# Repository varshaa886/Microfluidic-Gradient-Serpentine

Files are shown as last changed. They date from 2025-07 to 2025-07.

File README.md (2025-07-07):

# Microfluidic-Gradient-Serpentine
Analysis of dye diffusion and gradient formation in a 3 cm serpentine microchannel designed for microfluidic experiments using SolidWorks and 3D-printed molds.

Course: ME224 – Microscale Flows
Department of Mechanical Engineering, IIT Indore
Course Coordinator: Dr. Vijai Laxmi (Assistant Professor)
Team Members:

Sumit Sarkar (230003075)

Sri Varsha Dodda (230003074)

Shreeyut Maheshwari (230003071)

Project Title
Studying Diffusion and Fluid Flow for Gradient Formation in Microfluidic Platforms

Overview
This project explores the dynamics of fluid mixing and diffusion in microfluidic channels to create controlled concentration gradients. A serpentine microfluidic mixer was designed, simulated, and fabricated for biomedical and chemical mixing applications such as drug screening and lab-on-a-chip devices.

Literature Review
The design and methodology were inspired by the following research works:

Paper 1: Microfluidic systems using laminar flow splitting and recombination for static and dynamic gradients.

Paper 2: Comparative study on gradient generators including tree-shaped, Y-junction, and pressure balance systems.

Objective
To study and analyze fluid flow and diffusion-based gradient formation in a microfluidic serpentine channel, using numerical simulations and experimental validation.

Methodology
1. CAD Modelling
Designed a serpentine microchannel with two inlets and one outlet.

Dimensions: 40mm × 47mm with a total channel length of 31.75mm.

2. Simulation (ANSYS Fluent 2024 R1)
Eulerian Mixture Model for laminar flow (Re < 1).

Governing equations: Continuity, Momentum, and Species Transport (Fick's Law).

Boundary conditions: Specified inlet velocity, gauge pressure outlet.

3. Fabrication
Soft lithography using PDMS and resin mold.

Device bonded to a glass substrate.

4. Experimentation
Injected red and blue dye solutions at a flow rate of 0.2 ml/min.

Observed mixing behavior and gradient formation.

Results & Analysis
Hydraulic Diameter (Dh): 204.87 µm

Reynolds Number (Re): 0.02

Peclet Number (Pe): 205 (advection-dominated transport)

Achieved uniform gradients under different inlet velocity ratios (1:1 and 1:2).

Observed anomalous diffusion behavior.

Numerical vs Analytical Hydraulic Resistance: ~6% error only.

Conclusion
A controllable concentration gradient was successfully achieved through a serpentine microfluidic design.

Simulation and experimental results confirm the role of inlet velocity in gradient slope control.

Analytical and numerical agreement shows the model's reliability.

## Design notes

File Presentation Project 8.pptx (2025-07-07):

## ME224 - Microscale Flows

Studying Diffusion and Fluid flow for gradient Formation in microfluidic platforms

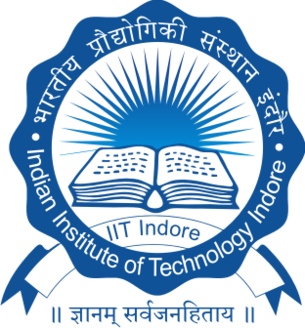
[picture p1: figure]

Department of Mechanical Engineering
Indian Institute of Technology Indore

Course Coordinator :
Dr. Vijai Laxmi
Assistant Professor
Department of Mechanical Engineering

Presented by :
Group Members
Sumit Sarkar(230003075)
Sri Varsha Dodda(230003074)
Shreeyut Maheshwari(230003071)

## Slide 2

Content

- Introduction
- Literature review
- Motivation and Objective
- Methodology
- Results and discussions
- Conclusion
- Future scope
- References

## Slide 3

Introduction

Microfluidic systems are widely used for precise fluid control in biomedical, chemical, and analytical applications. This project focuses on designing a serpentine microfluidic mixer to create a controlled gradient by mixing two inlet streams: red and blue resulting in a purple gradient transition.

The design was simulated in ANSYS Fluent to analyze fluid flow and diffusion. It was then fabricated using PDMS and a curing agent, molded, and baked. This study optimizes gradient formation for lab-on-a-chip and chemical mixing applications.

Reference of image: Link (https://ht.cnhealthshining.net/digital-thermometer/blood-analyzer-machine.html)

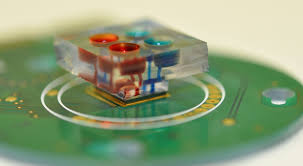
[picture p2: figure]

Fig. 1 Bioengineering Application

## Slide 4

Literature Review

- Our Project was mainly based on two Research Papers:
  - Paper 1[1]: This study presents a microfluidic system that generates precise gradients through controlled mixing of laminar flows. It achieves this by splitting, mixing, and recombining streams, allowing for both static (fixed) and dynamic (adjustable) gradient profiles based on flow rate variations.

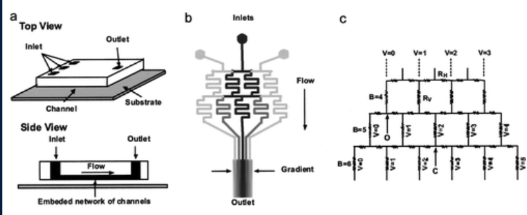
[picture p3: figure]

Literature Review

Fig. 1[¹] (a) Scheme of the PDMS microfluidic gradient generator used in this work. (b) Schematic design of a representative gradient-generating microfluidic network.(c) Equivalent electronic circuit model of the pyramidal microfluidic network.

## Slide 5

Literature Review

Our Project was mainly based on two Research Papers:
- Paper 2[2]: Various gradient generators in microfluidics were analyzed, highlighting their pros and cons.
- Tree-shaped networks create gradients by branching and recombining streams, while altered tree networks address limitations of traditional designs.

Literature Review

- Y-junctions rely on diffusion, membrane systems use porous barriers, and pressure balance systems prevent convection by equalizing inlet and outlet pressures.

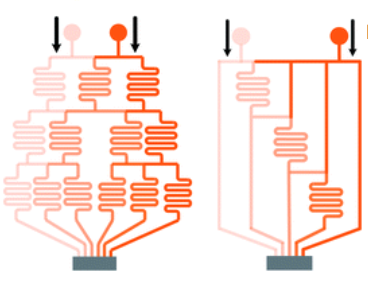
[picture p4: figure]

Fig2[2].Altered Tree Shape Diagram

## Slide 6

Motivation and objectives

Motivation
- Microfluidic systems are essential in biomedical and chemical research, enabling precise fluid control for applications like drug screening, tissue engineering, and chemical analysis. Efficient gradient formation is critical for these processes, requiring a deep understanding of diffusion and fluid flow dynamics in microchannels. This project aims to enhance microfluidic design for optimized gradient generation, contributing to advancements in lab-on-a-chip technology and controlled chemical mixing.

Objective
- To study diffusion and fluid flow dynamics for gradient formation in microfluidic platforms by designing a serpentine mixer, simulating fluid behavior in ANSYS Fluent, and fabricating the device using PDMS.

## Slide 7

Methodology

- Research Phase
  - We reviewed papers on gradient formation to understand diffusion dynamics and microfluidic mixing strategies

- Cad Modelling
  - The microfluidic mixer features three serpentine channels with two inlets for red and blue fluids. A single outlet allows observation of the resulting purple gradient formation.
  - Total Length : 31.75 mm
  - 40 mm by 47 mm Mold

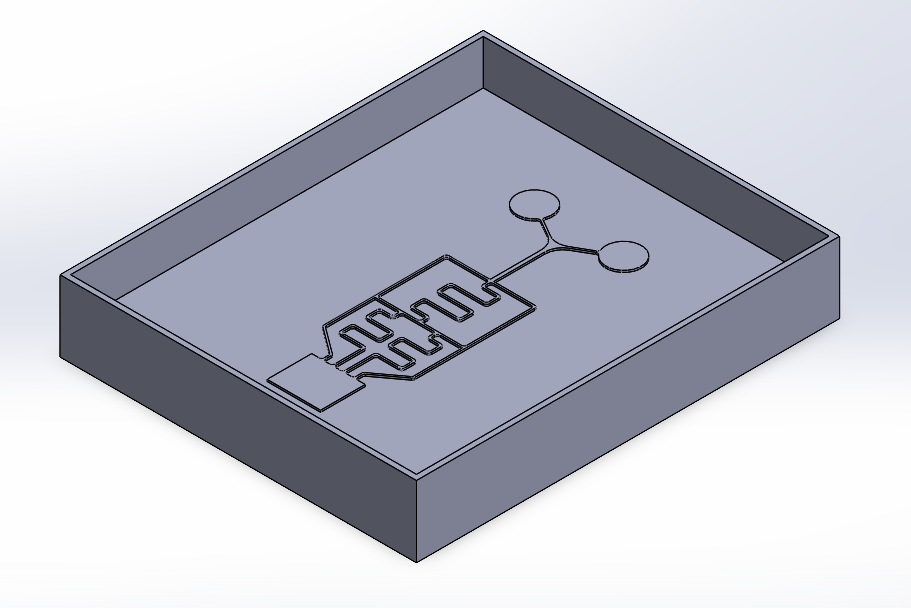
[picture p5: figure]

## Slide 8

Methodology

- Simulation
  - Simlulated on Ansys Fluent 2024 R1
  - We used the Eulerian mixture model for laminar flow (Re<1). Continuity , Momentum equations solved and Species Transport to apply Fick’s law of diffusion.
  - Boundary Conditions
    - Inlet Velocity
    - Gauge Pressure = 0 along with no shear

- Fabrication
  - Soft Lithography
  - The resin mold was fabricated, cleaned, and cured. PDMS was poured, baked, peeled off, and bonded to a glass plate.

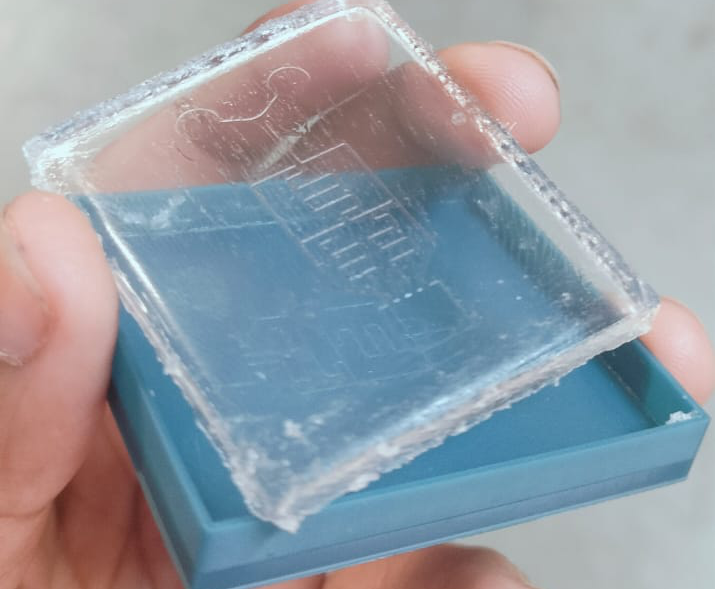
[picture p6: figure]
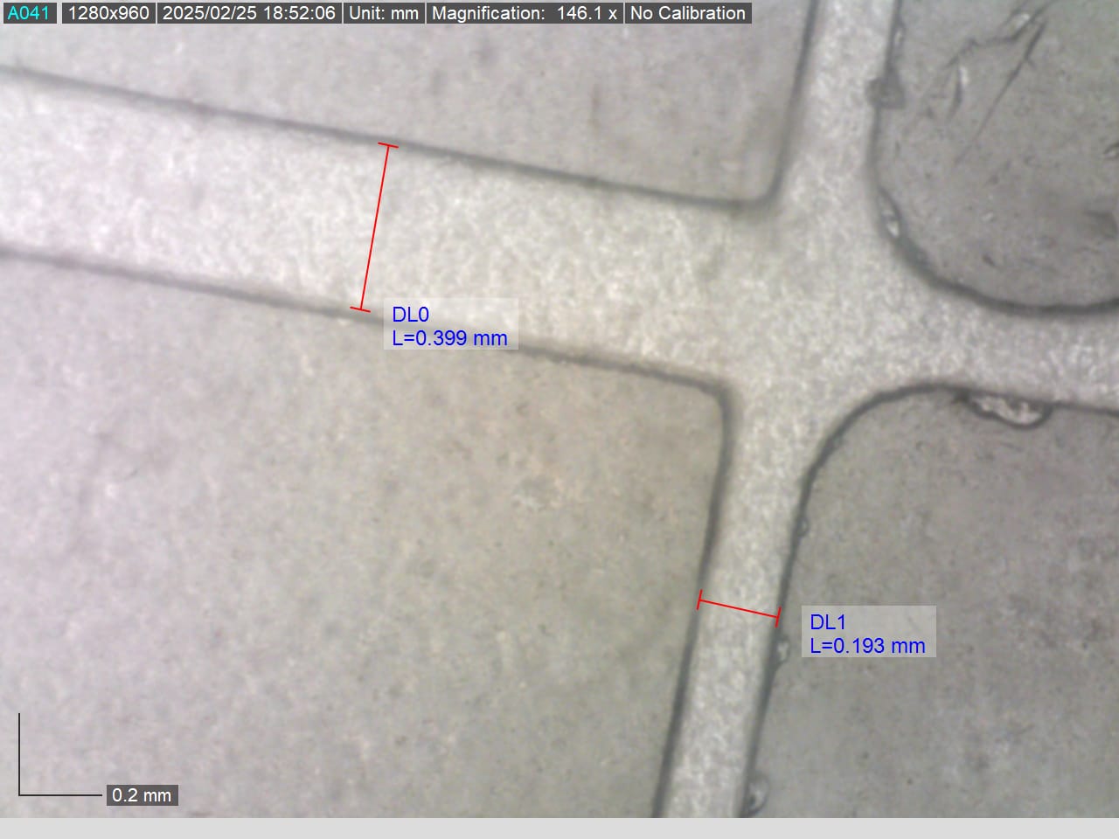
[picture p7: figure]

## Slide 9

Methodology

- Experimenting
  - Preparation of Dyes: Two separate dye solutions, red and blue, were prepared.
  - Injection into Inlets: The dyes were carefully poured into their respective microfluidic inlets.A volume flow rate of 0.2ml/min was set.
  - Gradient Formation: As the fluids traveled through the serpentine channels, controlled mixing occurred.

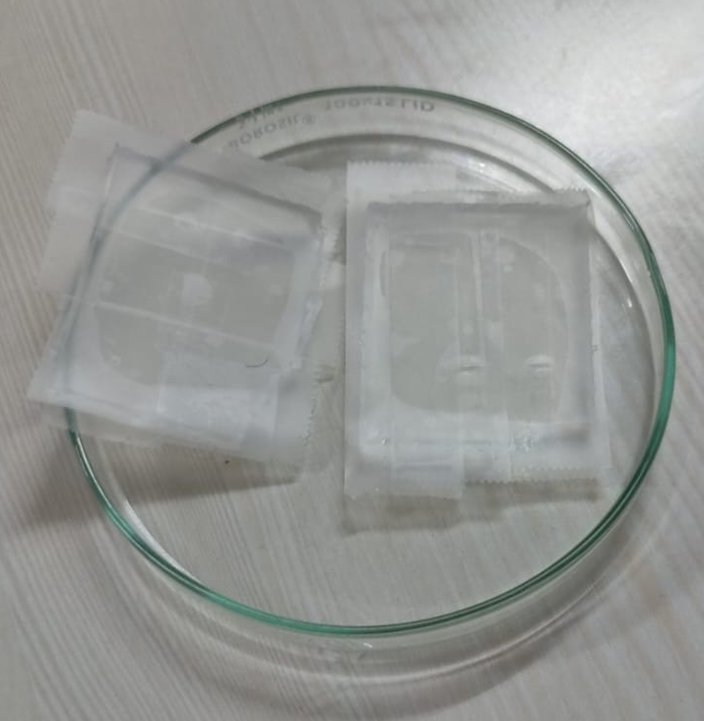
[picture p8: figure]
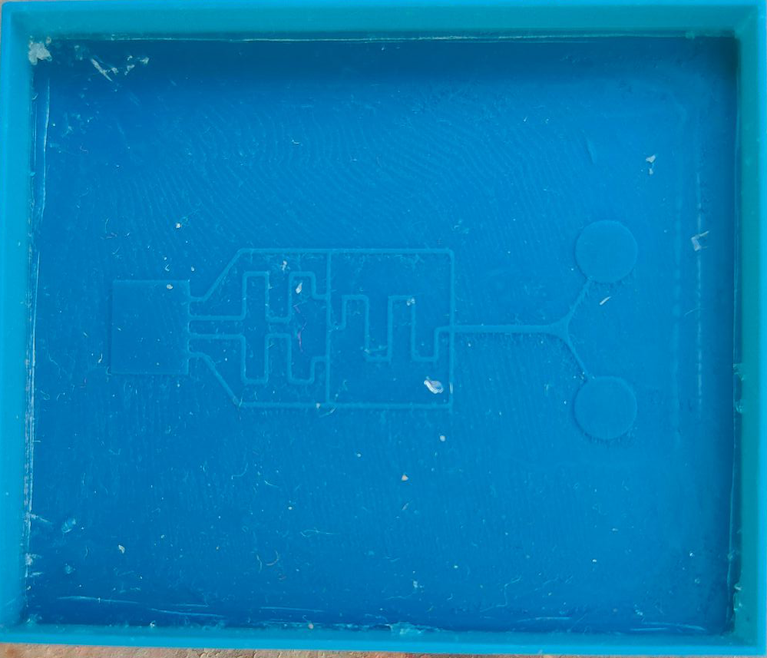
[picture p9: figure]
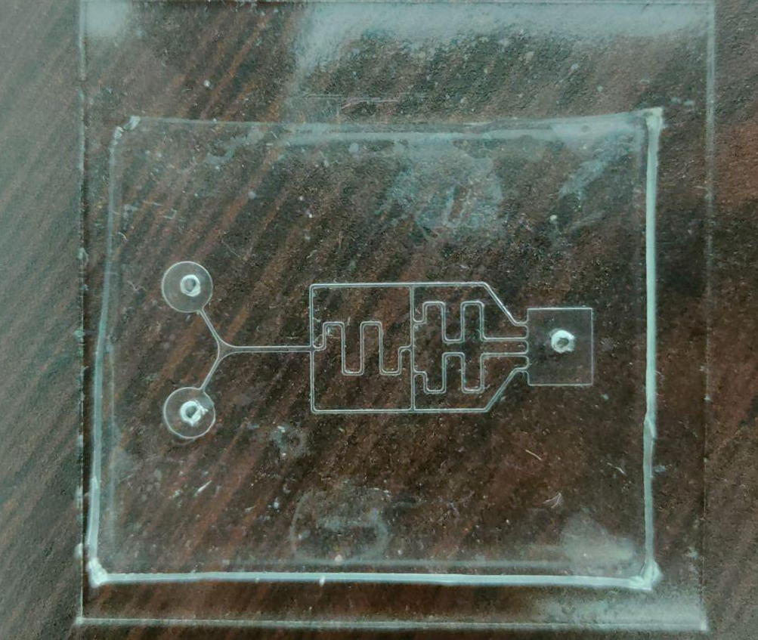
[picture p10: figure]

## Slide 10

Results and discussion

Calculation :
Hydraulic Diameter Dh: where A = Cross Section and P is wetted perimeter
Dh = 4A/P = 204.87 microns
Reynolds Number:
Re = ρvDh/μ = 0.02
Peclet Number:
Pe = Dhv/D = 205
For water, the diffusivity D is 10^−10 m2/s.
Since Pe > 1, advection is stronger than diffusion, but not significantly

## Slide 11

Results and discussion

- Base Case (Both the inlets have velocity of 1e-4 m/s).
- In the graph we can see that the volume fraction of water with red dye is decreasing.
- Overall a uniform Gradient is obtained ,which ensures the mixing is proper and uniform inside the serpentine channels.

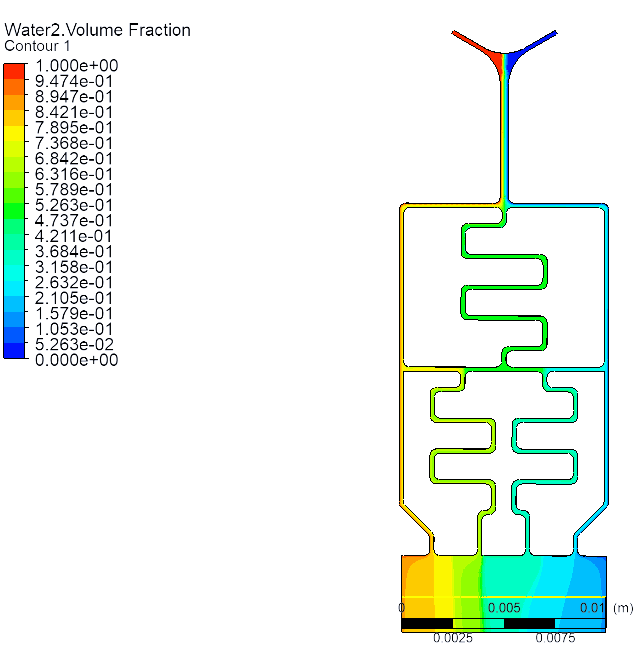
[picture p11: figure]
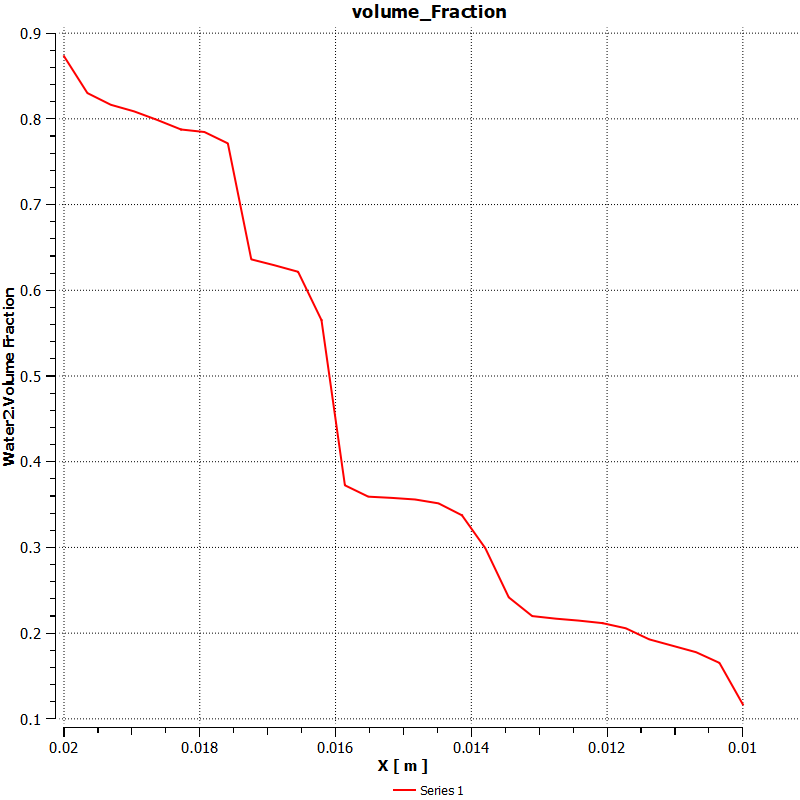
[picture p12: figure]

Fig.2 Volume_Fraction (Graph)
at the outlet

Fig.1 Volume fraction contour plot of Fluid water with red coloured dye

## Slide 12

Results and discussion

- The volume fraction at neck shows proper diffusion in the beginning of the microfluidic device.
- Also considered steady so by ficks law gradient of concentration should be constant .
dC/dt=D*d2C/dx2 where dc/dt =0
C = ax+b
which means it varies linearly with distance
- Anomalous Diffusion - as the concentration gradient is not perfectly linear and has some deviations with x.

Fig 3 Volume_Fraction (Graph)
at the Y-Bifurcation

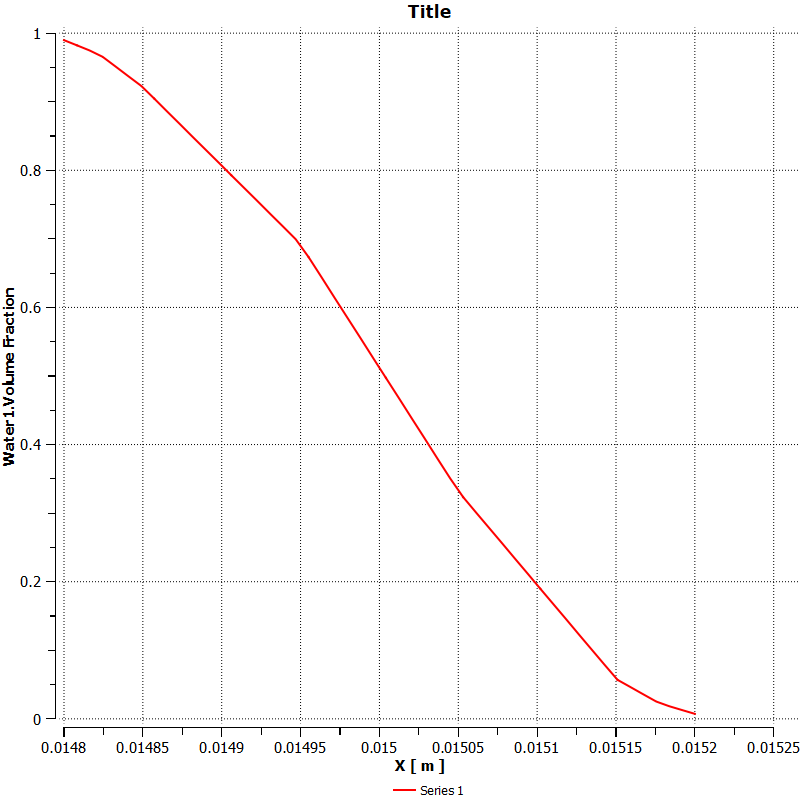
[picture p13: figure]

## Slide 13

Results and discussion

- The numerical pressure difference was calculated as 0.673 Pa with a velocity of 6.95 × 10⁻⁵ m/s in the branch.
- The numerical flow rate(Q) was determined to be 2.919 × 10⁻¹² m³/s.
- The numerical hydraulic resistance was 2.09 × 10⁸ Pa·s/m³, while the analytical value was
(28 mu L/h^4)
Rh = 28*10^-3*12.22*10^-3/(204*10^-6)^4
Rh = 1.97 × 10⁸ Pa·s/m³
- The error between numerical and analytical solutions was (2.09-1.97/1.97)*100 = 6.09%

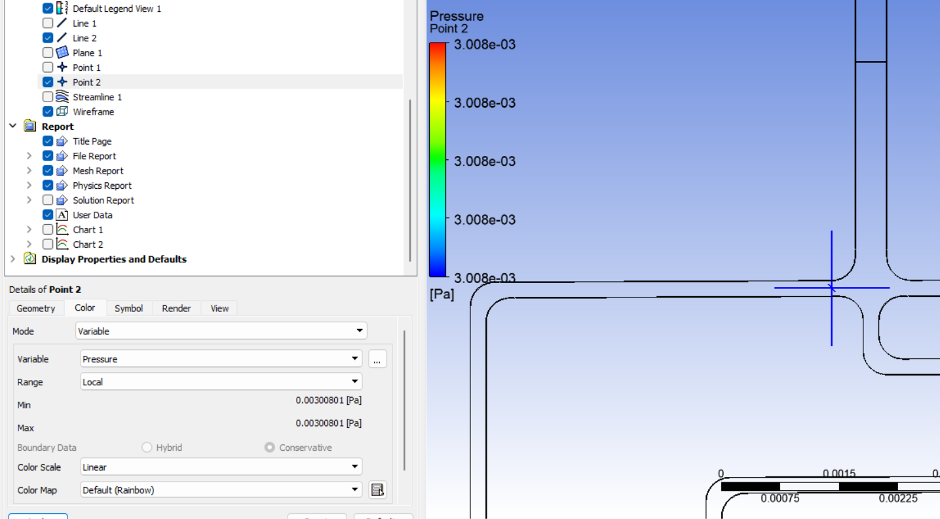
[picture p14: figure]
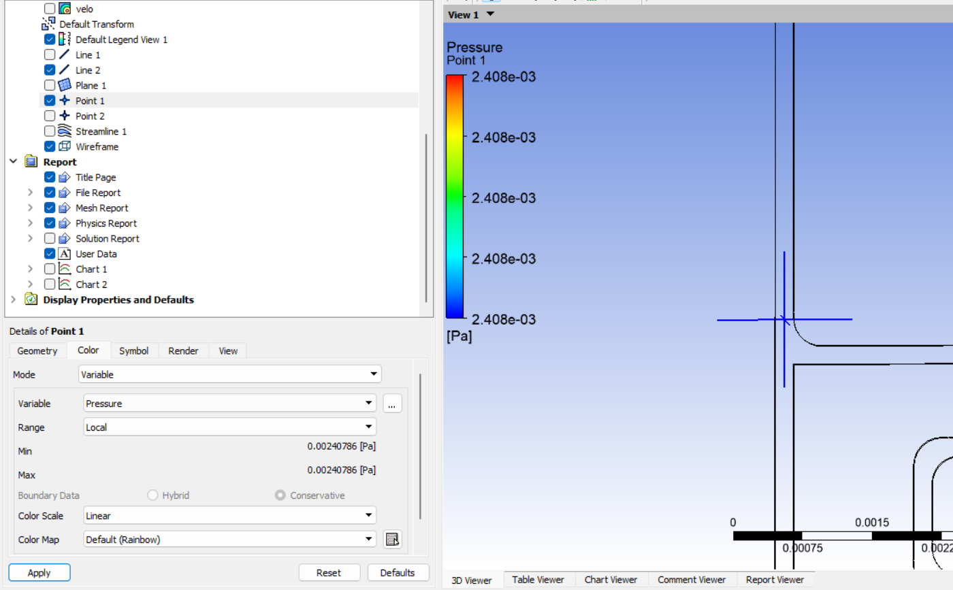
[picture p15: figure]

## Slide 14

Results and discussion

- Velocity Ratio= 1:2 Case (Inlets have velocity of 5e-5 m/s and 1e-4 m/s respectively )
- In the graph we can see that the volume fraction of water with red dye is decreasing more gradually.
- A uniform gradient was observed for the red dye due to its higher velocity. This indicates that achieving a low-slope gradient requires increasing the flow rate of the respective fluid.

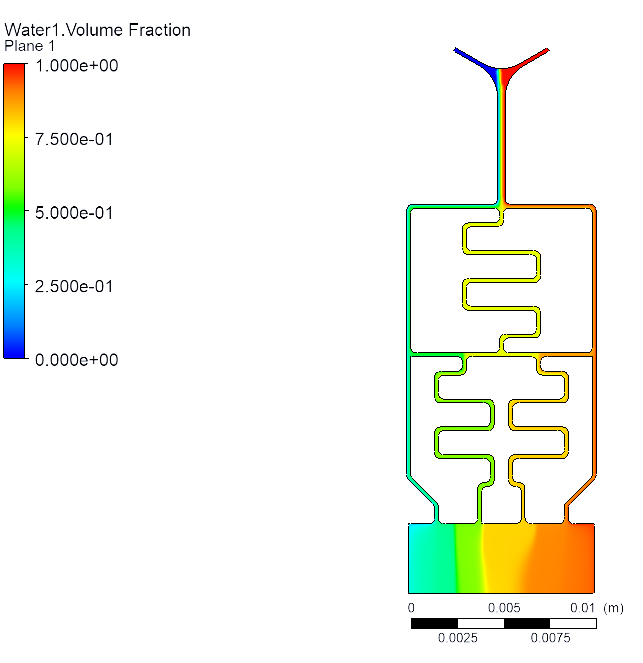
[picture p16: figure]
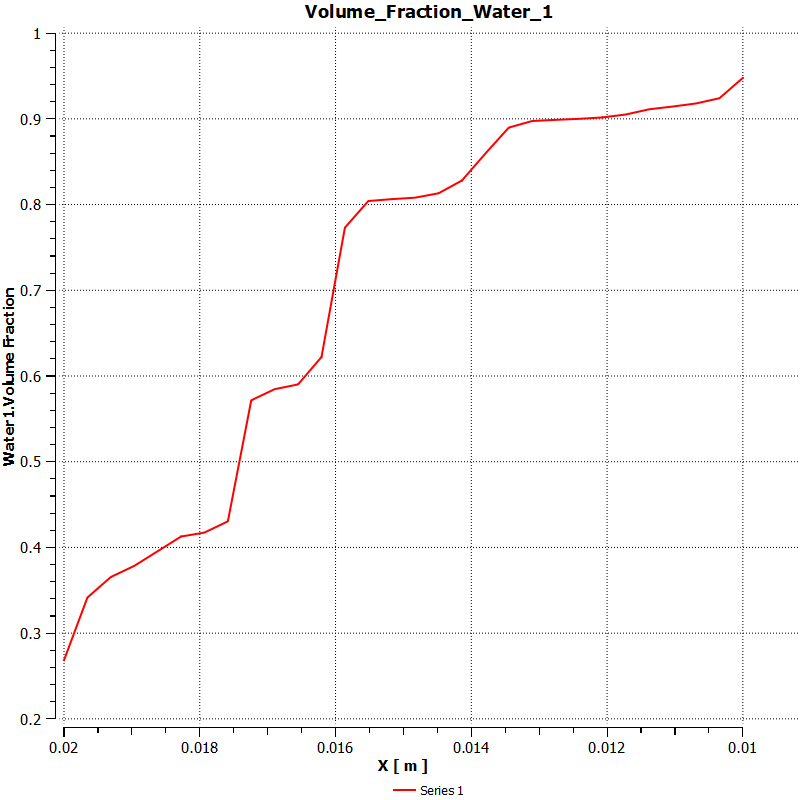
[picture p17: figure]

Fig.5 Volume_Fraction (Graph)
at the outlet

Fig.4 volume fraction contour plot of Fluid water with red coloured dye(Velocity 1:2)

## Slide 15

Results and discussion

- This curve represents the volume fraction of water 1 (Red dye) with distance at the Y bifurcation.
- It's not linear again shows that our case is anomalous diffusion

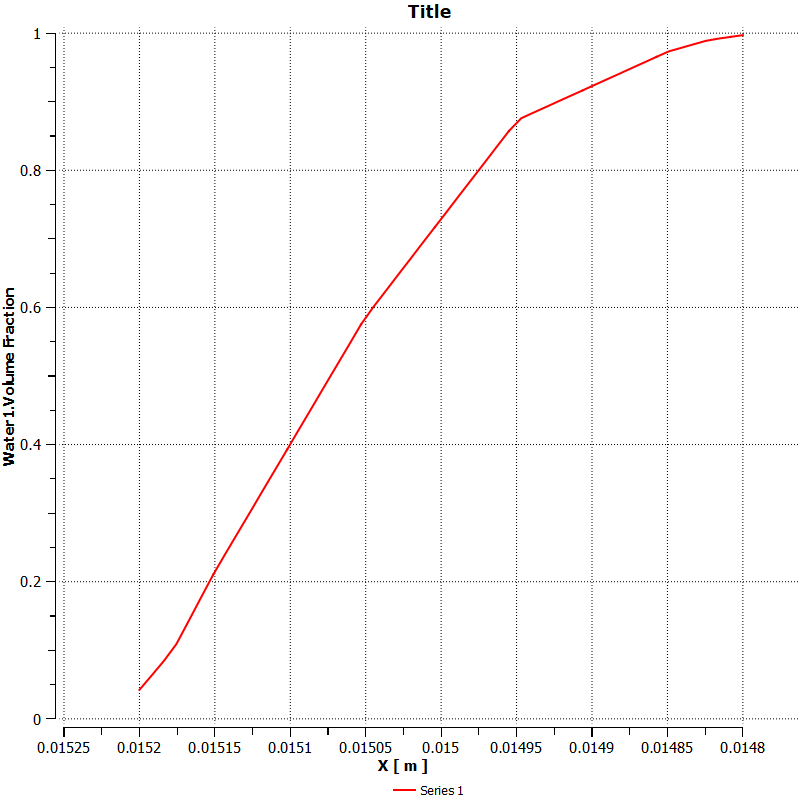
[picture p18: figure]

Fig.6 Volume_Fraction (Graph)
at the Y-Bifurcation

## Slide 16

Results and discussion

- The distance of interface and wall is given by d(Q2/(Q1+Q2)).
- In the Base Case, velocity Ratio is 1:1.
Q2=Q1
- Thickness = d/2 where d= 400 microns
- Thickness = 200 microns
- In the Second Case, velocity Ratio is 1:2.
Q2=4Q1
- Thickness=4d/5 where d= 400 microns
- Thickness = 320 microns

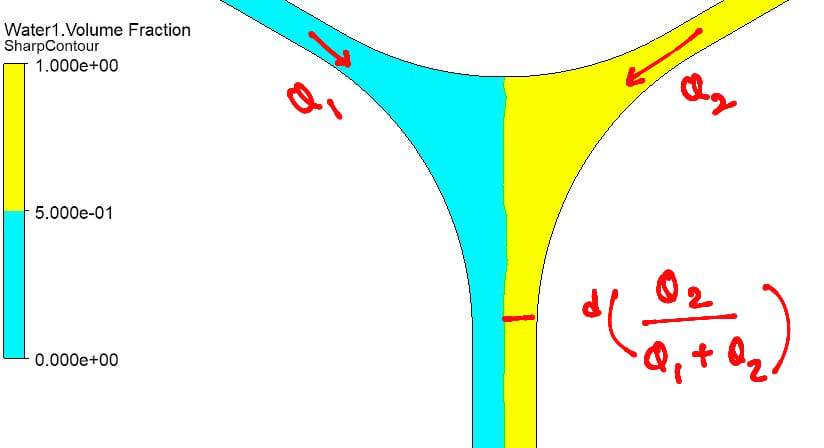
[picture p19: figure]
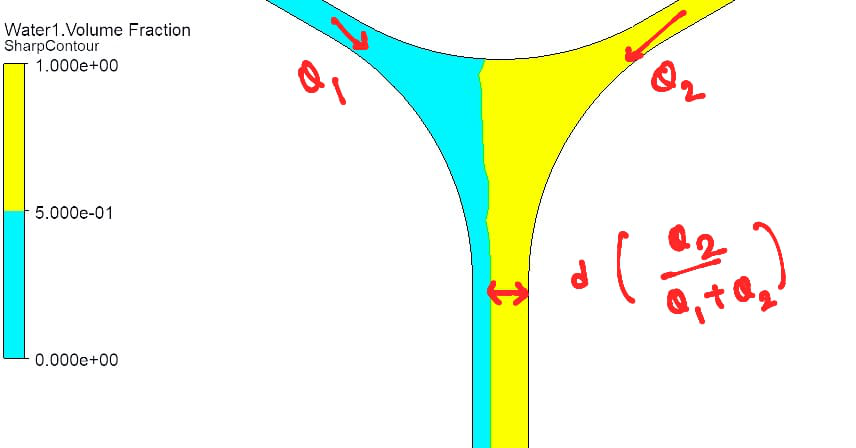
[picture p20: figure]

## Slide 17

Experimental Results:

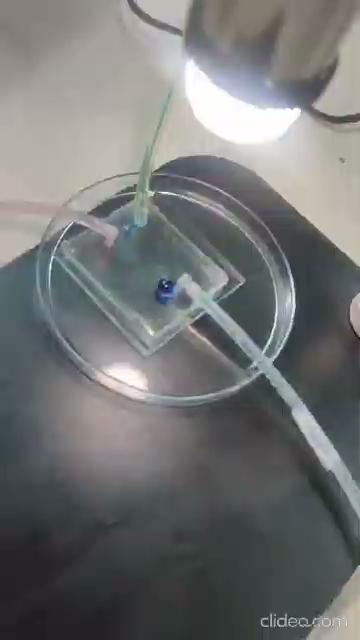
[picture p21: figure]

Results and discussion

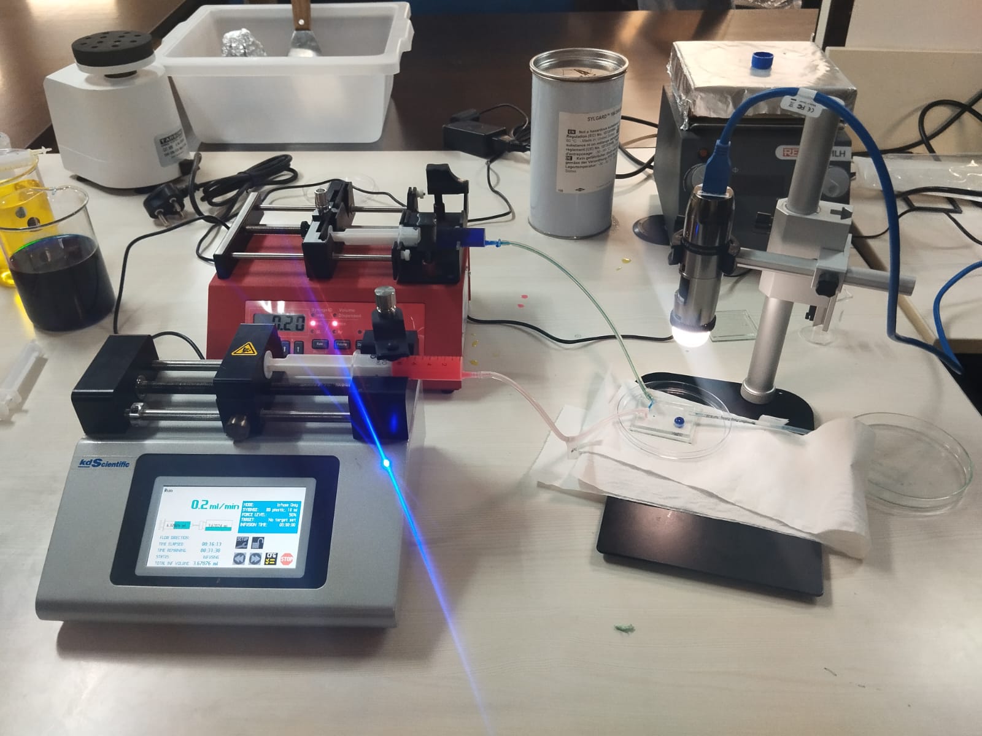
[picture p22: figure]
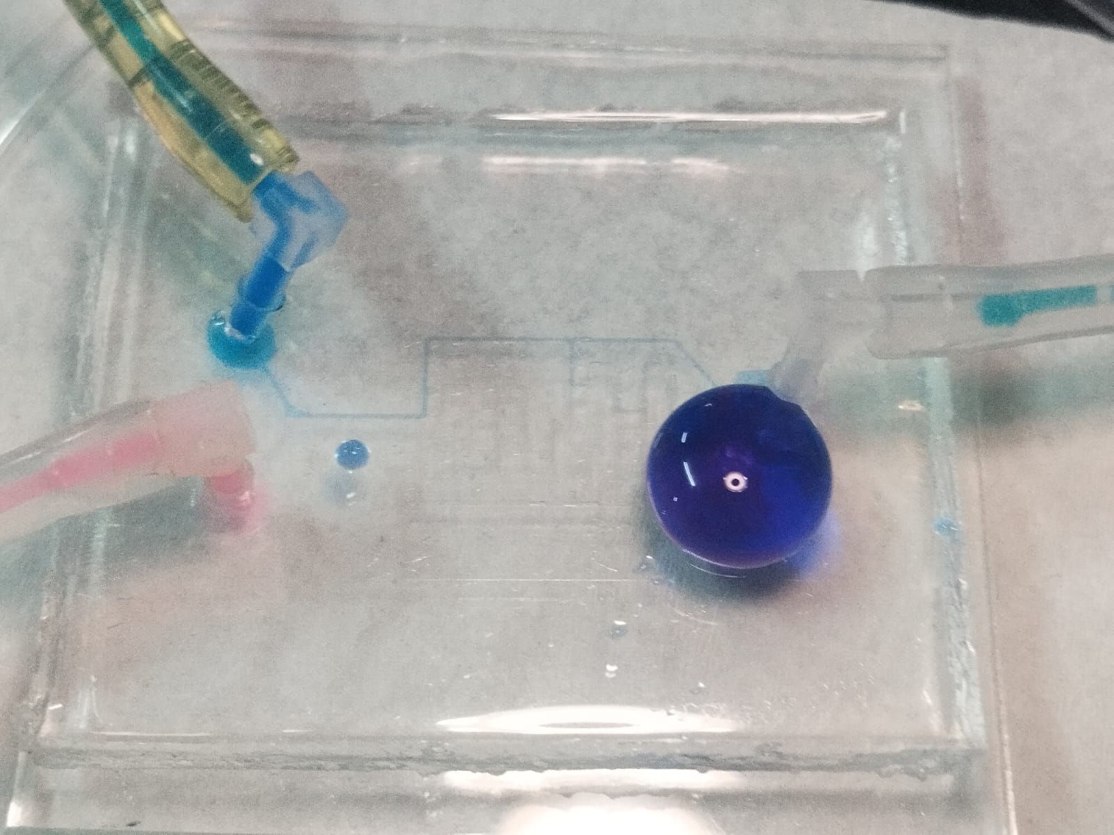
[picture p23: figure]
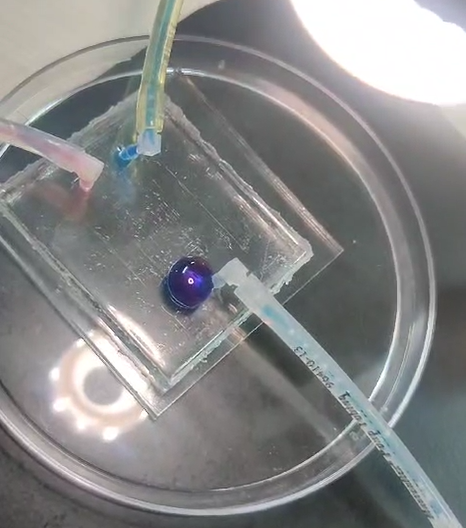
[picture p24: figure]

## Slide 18

Conclusions

- A uniform gradient was achieved, ensuring proper mixing in the serpentine channels.
- Anomalous diffusion was observed, as the concentration gradient resembles with the concentration profile of anomalous diffusion.
- Higher flow rates resulted in a lower-slope gradient, confirming the impact of velocity on gradient formation.
- The numerical hydraulic resistance closely matched the analytical value, with a 6.09% error.
- The study emphasizes the role of flow control in optimizing microfluidic mixing for biomedical and chemical applications

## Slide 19

Future scope

This research can be further developed in several ways to enhance the design, simulation accuracy, and practical applications of the microfluidic mixer:
- Multiphysics Simulations – Incorporating factors like fluid viscosity variations, electrokinetic effects, and heat transfer in simulations could provide a more comprehensive understanding of mixing behavior.
- Parametric Optimization – Conducting extensive simulations to analyze the effects of flow rate variations, Reynolds number, and channel width on mixing efficiency can lead to an optimized design.
- Scalability and Miniaturization – Developing designs for compact, high-throughput microfluidic devices can facilitate integration into lab-on-a-chip platforms.

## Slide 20

References

[1]. Israelachvili, J. (2000) 'Generation of solution and surface gradients using microfluidic systems', Langmuir, 16(5), pp. 1891–1895.
[2]. Wang, X., Liu, Z. and Pang, Y. (2017) 'Concentration gradient generation methods based on microfluidic systems', (https://pubs.rsc.org/en/content/articlehtml/2017/ra/c7ra04494a)RSC Advances (https://pubs.rsc.org/en/content/articlehtml/2017/ra/c7ra04494a), 7(44), pp. 27711–27745. (https://pubs.rsc.org/en/content/articlehtml/2017/ra/c7ra04494a)

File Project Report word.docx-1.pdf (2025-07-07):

### Studying Diffusion and Fluid flow for gradient Formation in microfluidic platforms

ME224,Fundamental of
Microscale Flows
Submitted by

Shreeyut Maheswari 230003071 Sri Varsha Dodda 230003074 Sumit Sarkar 230003075

Course Coordinator:
Dr. Vijai Laxmi, Assistant Professor, ME


Department of Mechanical Engineering Indian Institute of Technology, Indore

### Abstract

- Microfluidic systems enable precise manipulation of fluids at the microscale, making them indispensable for biomedical, chemical, and analytical applications. These systems play a critical role in lab-on-a-chip technologies, where controlled gradient formation is essential for processes such as drug screening, cell migration studies, and chemical synthesis. This study focuses on the design, simulation, and fabrication of a serpentine microfluidic mixer optimized for gradient generation by mixing two inlet streams of red and blue fluids, resulting in a controlled concentration gradient.
- Computational simulations were conducted using ANSYS Fluent to analyze flow behavior and diffusion characteristics. The Eulerian mixture model was employed to simulate laminar flow and species transport, incorporating Fick’s Law to evaluate diffusion dynamics. The device was then fabricated using soft lithography with PDMS, ensuring compatibility with biological and chemical applications. Experimental validation was performed by injecting dyes at controlled flow rates to visualize gradient formation.
- The results demonstrated efficient and uniform gradient formation, with numerical and analytical hydraulic resistance values showing close agreement, with a 6.09% error. The study also observed anomalous diffusion effects, indicating non-ideal mixing characteristics. Additionally, velocity-dependent gradient control was identified, suggesting that adjusting flow rates can fine-tune gradient profiles. These findings contribute to the optimization of microfluidic mixing strategies, offering improvements for biomedical applications such as tissue engineering, targeted drug delivery, and high-throughput chemical screening.

### Content

1. Introduction |
2. Literature Review |
3. Motivation and Objective |
4. Methodology |
5. Results and Discussion |
6. Conclusions |
7. Future scope |

References

### 1. Introduction

Microfluidic systems are widely used for controlled fluid handling in biomedical, chemical, and analytical applications. These platforms enable precise control over chemical gradients, crucial for applications such as drug screening, tissue engineering, and chemical analysis. In biomedical research, gradient generators are essential for cell migration studies, morphogen gradient analysis, and high-throughput screening of drug responses. Chemical and material science applications also benefit from microfluidic gradient generators by enabling controlled reactions, nanoparticle synthesis, and localized surface modifications.

The challenge in microfluidic gradient generation lies in the interplay between advection and diffusion, governed by the Peclet number. When diffusion dominates, gradients form slowly, requiring longer microchannels. Conversely, when advection dominates, gradients may not develop uniformly, necessitating specialized channel designs such as serpentine structures, tree-shaped networks, and membrane-based diffusers. The precise design of these systems must account for factors such as Reynolds number, flow rates, and species transport dynamics to achieve desired gradient profiles.

This project aims to develop a serpentine microfluidic mixer optimized for controlled gradient formation. By leveraging computational fluid dynamics (CFD) simulations and experimental validation, we analyze how mixing efficiency and diffusion dynamics impact gradient uniformity. The ultimate goal is to enhance the performance of lab-on-a-chip systems, providing reliable and scalable solutions for biomedical and chemical applications. The integration of numerical simulations with experimental validation ensures an in-depth understanding of the microfluidic system's behavior, contributing to the ongoing advancements in microfluidic technology.

### 2. Literature Review

### 2.1. Generation of Solution and Surface Gradients Using Microfluidic Systems-by Noo

Li Jeon, Stephan K. W. Dertinger
Introduced a microfluidic system that generates precise gradients using controlled mixing of laminar flows in microchannels.This system creates gradients by splitting, mixing, and recombining fluid streams. It can produce static gradients (fixed profiles) or dynamic gradients (adjustable profiles by changing flow rates).

### 2.2. Concentration gradient generation methods based on microfluidic systems

-by Xiang Wang , Zhaomiao Liu * and Yan Pang
Different type of Gradient generators in Microfluidics with there respective advantages and disadvantages Namely-
- Tree Shape Networks - Network involving branching and recombining streams to create gradient
- Altered Tree Shape Network - Modified tree-shape networks aim to reduce limitations of traditional designs.
- Y Shape Junctions - generates gradients through molecular diffusion between streams.
- Membrane system - use porous materials to seperate flowing streams from the gradient chamber
- Pressure Balance system - these systems balance inlet and outlet pressures to elimination convection in gradient chamber


Fig 1 : Types of MicroFluidic Gradient generators

### 3. Motivation and Objective

### 3.1. Motivation:

Motivation behind this project is that Microfluidic systems are essential in biomedical and chemical research, enabling precise fluid control for applications like drug screening, tissue engineering, and chemical analysis. Efficient gradient formation is critical for these processes, requiring a deep understanding of diffusion and fluid flow dynamics in microchannels. This project aims to enhance microfluidic design for optimized gradient generation, contributing to advancements in lab-on-a-chip technology and controlled chemical mixing.

### 3.2. Objective:

- Investigate diffusion and flow dynamics in microfluidic platforms to improve gradient formation.
- Design and simulate a serpentine microfluidic gradient mixer using ANSYS Fluent.
- Fabricate the device using soft lithography techniques and validate its performance through experimental testing.
- Compare numerical and experimental results to assess the accuracy and efficiency of the proposed design.

### 4. Methodology

- Research Phase - Papers were reviewed on gradient formation to understand diffusion dynamics and microfluidic mixing strategies
- Cad modeling - The microfluidic mixer features three serpentine channels with two inlets for red and blue fluids. A single outlet allows observation of the resulting purple gradient formation with Total length - 31.75 mm and 40 mm by 47 mm Mold
- Simulation
- Simulation on Ansys Fluent 2024 R1
- We used the Eulerian mixture model for laminar flow (Re<1). Continuity , Momentum equations solved and Species Transport to apply Fick’s law of diffusion.
- Boundary Conditions
■ | Inlet Velocity
■ | Gauge Pressure = 0 along with no shear
- Fabrication
- Soft Lithography
- The resin mold was fabricated, cleaned, and cured. PDMS was poured, baked, peeled off, and bonded to a glass plate.
- Experimenting
- Preparation of Dyes: Two separate dye solutions, red and blue, were prepared.
- Injection into Inlets: The dyes were carefully poured into their respective microfluidic inlets.A volume flow rate of 0.2ml/min was set.
- Gradient Formation: As the fluids traveled through the serpentine channels, controlled mixing occurred.


Fig 2 : Photographs of Mold and Microfluidic device

### 5. Results and Discussion

## - Calculation:

Hydraulic Diameter Dh: where A = Cross Section and P is wetted perimeter

Dh = 4A/P = 204.87 microns

Reynolds Number:

Re = ρvDh/μ = 0.02 (indicating laminar flow)

Peclet Number:

Pe = Dhv/D = 205 (suggesting advection dominance over diffusion)

For water, the diffusivity D is 10^-10 m2/s.

## - Numerical Simulation:

In Base case (Both Inlets have velocity of 1e-4m/s).Overall a uniform Gradient is obtained,which ensures the mixing is proper and uniform inside the serpentine channels


Fig 3: Simulation result

The volume fraction at the neck shows proper diffusion in the beginning of microfluidic devices. Also considered steady so by ficks law the gradient of concentration should be constant (C = ax + b). Anomalous DIffusion - as the concentration gradient is not perfectly linear and has some deviation with X.

The numerical pressure difference was calculated as 0.673 Pa with a velocity of 6.95 × 10⁻⁵ m/s in the branch.The numerical flow rate(Q) was determined to be 2.919 × 10⁻¹² m³/s.
The numerical hydraulic resistance was 2.09 × 10⁸ Pa·s/m³, while the analytical value was
(28 mu L/h^4)
Rh = 28*10^-3*12.22*10^-3/(204*10^-6)^4
Rh = 1.97 × 10⁸ Pa·s/m³

The error between numerical and analytical solutions was (2.09-1.97/1.97)*100 = 6.09%

Velocity Ratio= 1:2 Case (Inlets have velocity of 5e-5 m/s and 1e-4 m/s respectively )
A uniform gradient was observed for the red dye due to its higher velocity. This indicates that achieving a low-slope gradient requires increasing the flow rate of the respective fluid.


The distance of interface and wall is given by d(Q2/(Q1+Q2)).

In the Base Case, velocity Ratio is 1:1.
Q2=Q1
Thickness = d/2 where d= 400 microns
Thickness = 200 microns

In the Second Case, velocity Ratio is 1:2. Q2=4Q1
Thickness=4d/5 where d= 400 microns Thickness = 320 microns

## - Experimental calculation:


Fig 4: Interface Distance

Mixing of red and blue coloured dyed water and observing the gradient formation.Not much information is gathered from experiment as the intensities of the dye are too low.

Fig 5: Outlet has violet coloured dye

Fig 6: Experimental Setup

### 6. Conclusions

- A uniform gradient was achieved, ensuring proper mixing in the serpentine channels.
- Anomalous diffusion was observed, as the concentration gradient resembles with the concentration profile of anomalous diffusion.
- Higher flow rates resulted in a lower-slope gradient, confirming the impact of velocity on gradient formation.
- The numerical hydraulic resistance closely matched the analytical value, with a 6.09% error.
- The study emphasizes the role of flow control in optimizing microfluidic mixing for biomedical and chemical application

### 7. Future Scope

- Geometric Optimization: Further refinement of microchannel designs to enhance gradient uniformity, minimizing flow disturbances and dead zones.
- Active Control Mechanisms: Integration of external actuators or flow regulators to enable real-time adjustment of gradient profiles for dynamic applications.
- Expanded Applications: Potential applications in drug delivery systems, tissue engineering models, and chemical reaction kinetics studies.
- Wastage Outlet Addition: Introducing a dedicated waste outlet to prevent flow disturbances and allow clearer visualization of the gradient within the main observation region.
- Electrokinetic and Thermal Effects: Exploring electrokinetic flow control for enhanced mixing, along with thermal convection methods for fluids with different temperatures to modify diffusion characteristics dynamically.

### References

[1]. Israelachvili, J. (2000) 'Generation of solution and surface gradients using microfluidic systems', Langmuir, 16(5), pp. 1891–1895.
[2]. Wang, X., Liu, Z. and Pang, Y. (2017) 'Concentration gradient generation methods based on microfluidic systems', RSC Advances, 7(44), pp. 27711–27745. (https://pubs.rsc.org/en/content/articlehtml/2017/ra/c7ra04494a)

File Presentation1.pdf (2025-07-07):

## ME 224 -FUNDAMENTALS OF MICROSCALE FLOWS

PROJECT 8

# Literature Review

### 1. Generation of Solution and Surface Gradients Using Microfluidic Systems

by Noo Li Jeon, Stephan K. W. Dertinger

Introduced a microfluidic system that generates precise gradients using controlled mixing of laminar flows in microchannels.
This system creates gradients by
splitting, mixing, and
recombining fluid streams. It
can produce static gradients (fixed profiles) or dynamic gradients (adjustable profiles by changing flow rates).


# Literature Review

2 . Concentration gradient generation methods based on microfluidic systems by Xiang Wang , Zhaomiao Liu * and Yan Pang

Different type of Gradient generators in Microfluidics with there respective advantages and disadvantages
Namely-Tree Shape Networks - Network involving branching and recombining streams to create gradient Altered Tree Shape Network - Modified tree-shape networks aim to reduce limitations of traditional designs.
Y Shape Junctions - generates gradients through molecular diffusion between streams. Membrane system - use porous materials to seperate flowing streams from the gradient chamber Pressure Balance system - these systems balance inlet and outlet pressures to eliminate convection in gradient chamber

LINK (https://pubs.rsc.org/en/content/articlehtml/2017/ra/c7ra04494a)

# Literature Review

### Tree-Shape Design along with Y-Shape Design

Membrane-Based Gradient Generators; Pressure Balance Method; Disadvantages:

Advantages:
High Gradient Resolution – Produces
smooth and continuous gradients with
fine concentration variations.
Other Ways

Scalability
Simple & Easy Fabrication
Cost-Effective
Suitable for Complex Gradient Profiles

Requires Precise Pressure Control
Complex Experimental Setup
High Cost

Fabrication Complexity
Slow Response Time

# Design


## Conjugate of Altertree tree and Y

1️⃣ Uniform Flow Distribution – Y-shape ensures balanced initial split, while Altertree refines it, preventing uneven flow.
2️⃣ Lower Pressure Drop – Y-branches reduce sudden pressure changes, and Altertree's gradual narrowing maintains smooth flow.
3️⃣ Better Mixing – Y-shape introduces controlled flow paths, and Altertree’s branching would help the mixing.

# Design

Serpentine Width

Dimensions are in mm

Rounded Corners
Prevents sharp transitions
Reducing vortex formation
Minimize entry turbulence
Prevents dead zones

Controlled microfluidic movement
Laminar flow
High Surface Area-to-Volume Ratio
Low Pressure Drop

# Methodology

## Simulation

We have used fluent(species transport,Euleiran model in multiphase).
Eulerian-Eularian Laminar Model in COMSOL Multiphysics.
Laminar model as reynold number will be less .
Inlet velocity would be 10^-4 m/s,Slip at walls
and guage pressure is set to 0.
From simulation we will be gathering information about how different parameters affect the gradient formation

### Then final design modifications based on the output and finally will verify it by fabricating the microfluidic deivce using PDMS

Parameters on which variation will be checked

Length of serpentine channel
Width of channel
Velocity Ratio
Density Ratio
Viscosity Ratio

# Metrics

### Resolution of gradient

Third week; Experimental Verification

Diffusion Length of Device
complexity in design
Material requirement for
manufacturing(cost)
Tentatives

First week
Simulation will be
completed

Second week
Fabrication of final
design


# Shreeyut Sri Varsha Sumit Sarkar

https://pubs.rsc.org/en/content/articlehtml/2017/ra/c7ra04494a

### Reference

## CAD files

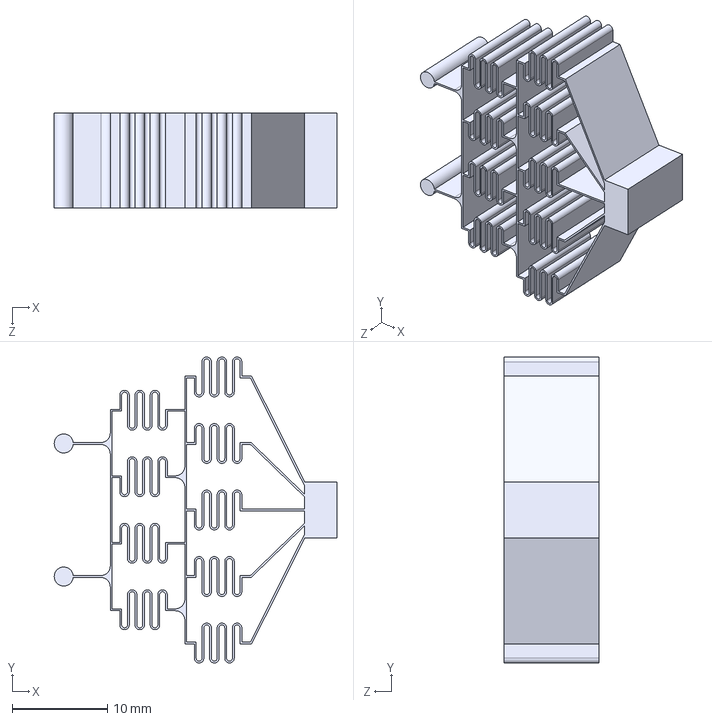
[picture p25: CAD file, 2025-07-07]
notmanufacturing.STEP
29.7 x 32.2 x 10.0 mm
